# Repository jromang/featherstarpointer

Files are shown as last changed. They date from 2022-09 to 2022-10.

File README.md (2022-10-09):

# Feather Star Pointer

:warning: **Azimuth accuracy is based on a magnetometer : so currently, you can have a 2° error margin in azimuth**

The goal of this project is to be a  simple star pointing system for push-to telescopes, using the [SkySafari Pro](https://skysafariastronomy.com/skysafari-7-professional-astronomy-telescope-control-software-for-android.html) application on your smartphone.

### Components
- [Adafruit Featherboard ESP32 V2](https://www.adafruit.com/product/5400)
- [Adafruit BNO055 Absolute Orientation Sensor](https://learn.adafruit.com/adafruit-bno055-absolute-orientation-sensor)
- [STEMMA QT / Qwiic JST SH 4-Pin Cable - 50mm Long](https://www.adafruit.com/product/4399)
- [Lithium Ion Polymer Battery](https://www.adafruit.com/product/3898)
- 3D printed case and holder (you will find [ready to print STL](https://github.com/jromang/featherstarpointer/tree/main/stl) files in this repo)
- A smartphone (Android/IOS) with the [SkySafari Pro](https://skysafariastronomy.com/skysafari-7-professional-astronomy-telescope-control-software-for-android.html) application
- Optional [Jack JST PH 2.0/2.0mm Male/Female](https://fr.aliexpress.com/item/1005002657347265.html?spm=a2g0o.order_list.0.0.21ef5e5bcTvBVH)
- Optional [Self locking switch](https://fr.aliexpress.com/item/4000164264475.html?spm=a2g0o.order_list.0.0.6cba5e5b0LTYn6)

### How to build
- There is not soldering involved, just connect the Featherboard, the sensor, and the battery with the cable connectors
- You will need to flash the [binary firmware](https://github.com/jromang/featherstarpointer/tree/main/sketch/fsp)  to the Featherboard
- You have to glue the 3D printed base to the 3d printed holder

### How to use
- Follow the [calibration procedure](https://learn.adafruit.com/adafruit-bno055-absolute-orientation-sensor/device-calibration) at startup : the white LED will turn red when the calibration is finished.
- Add the FSP as a 'basic encoder system' in skysafari, choose 'push-to  Alt-az', and connect using bluetooth. Finally set the encoder settings to +8192 (both fields).
- The red LED will start to blink when the battery is low.
- Enjoy !

### Pictures

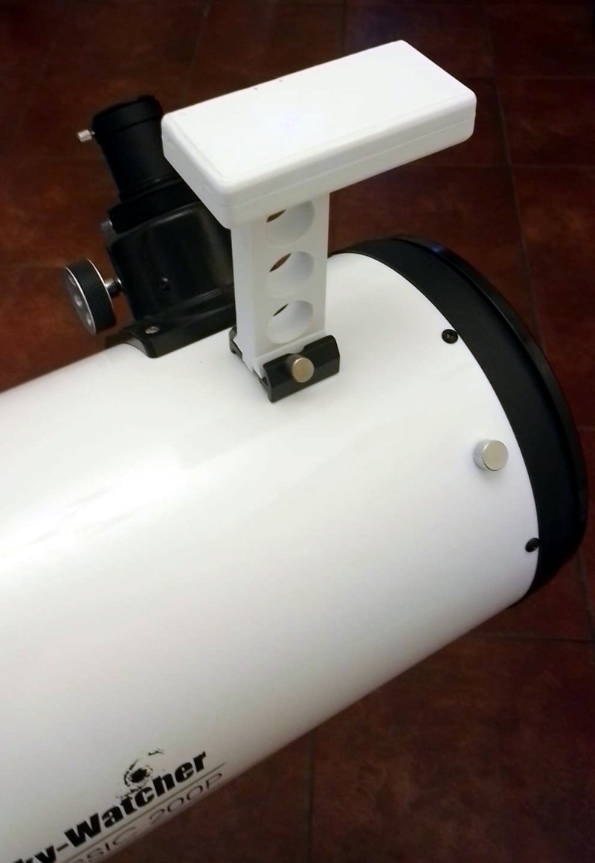
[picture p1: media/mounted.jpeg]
Mounted on scope
 
 
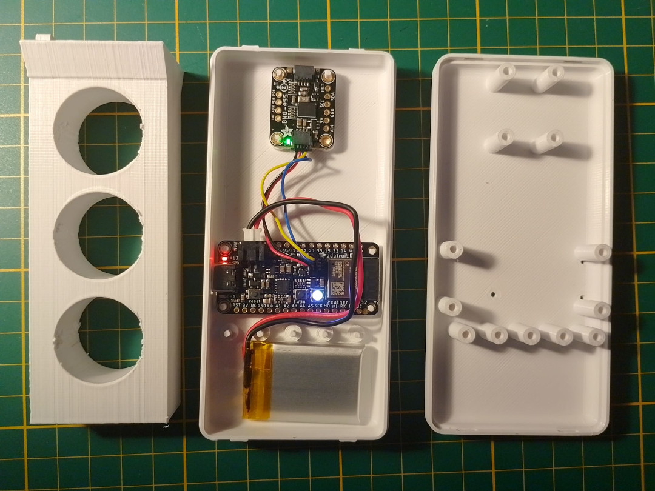
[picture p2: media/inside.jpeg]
Inside
 
 
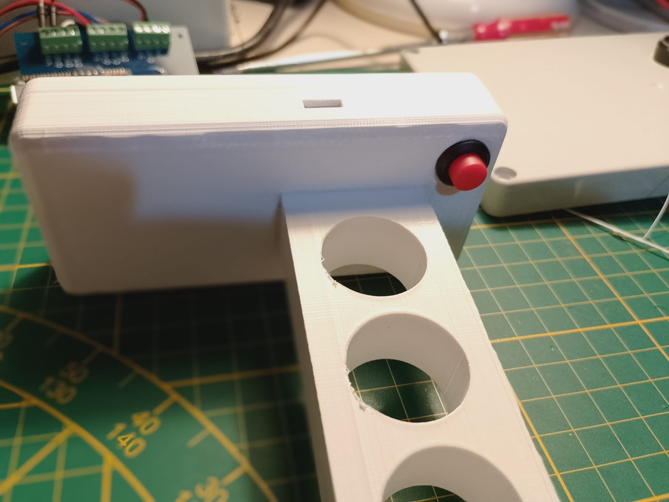
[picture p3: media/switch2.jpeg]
Switch
 
 
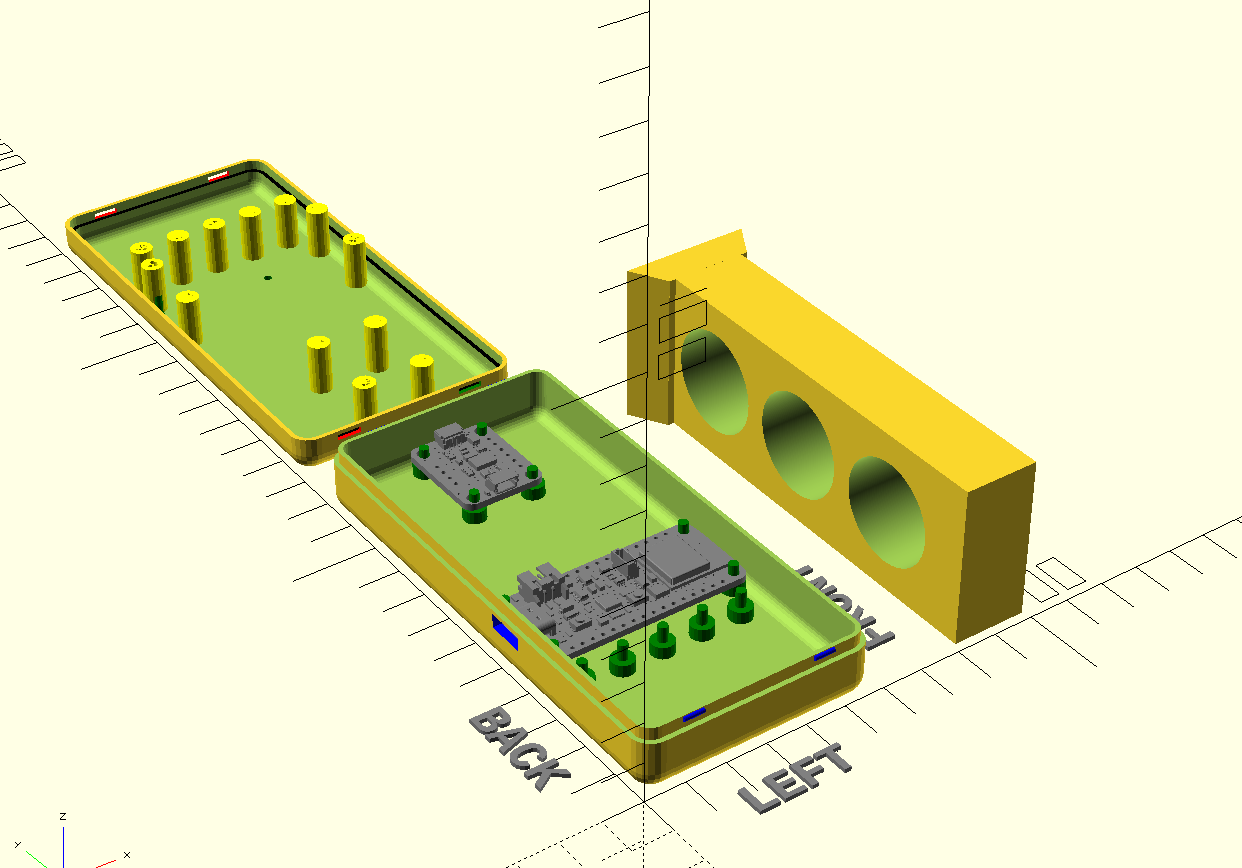
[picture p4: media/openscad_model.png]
3D Model
 
 
 SkySafari

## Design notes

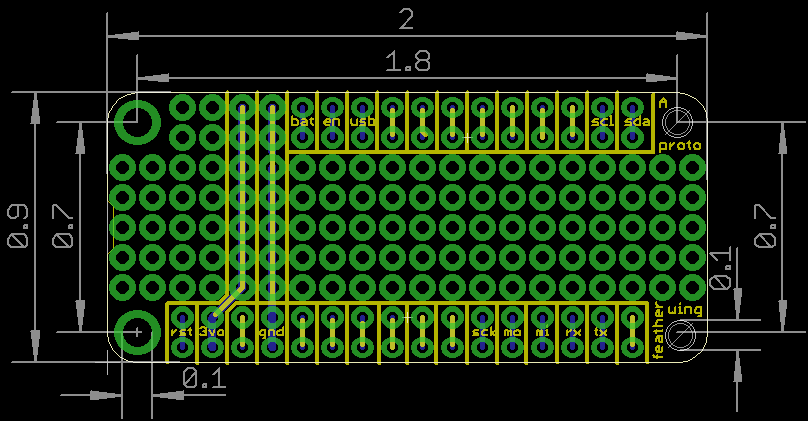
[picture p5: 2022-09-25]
openscad/specs/arduino_adafruit_products_fabprint.png

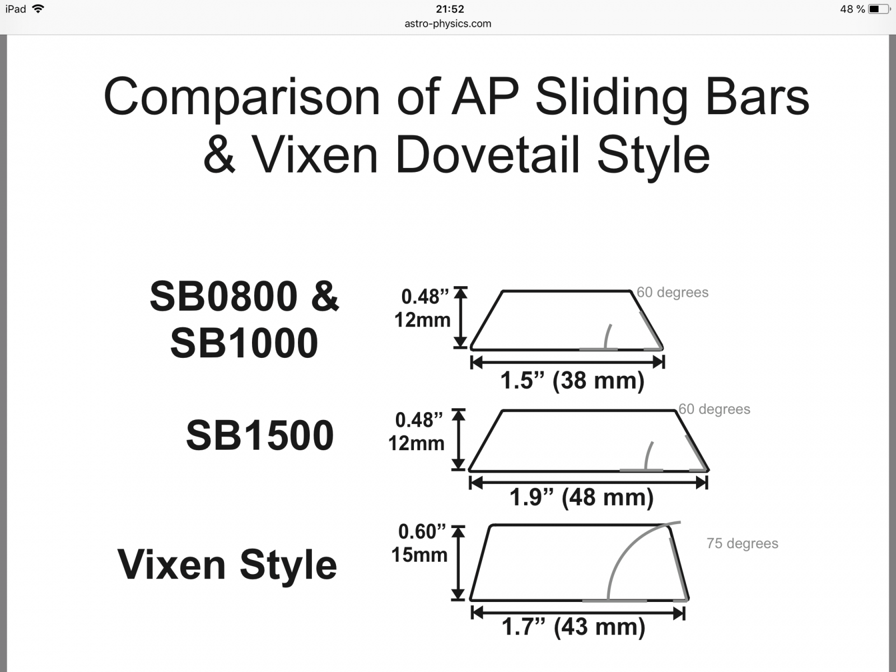
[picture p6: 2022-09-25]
openscad/specs/vixen.png

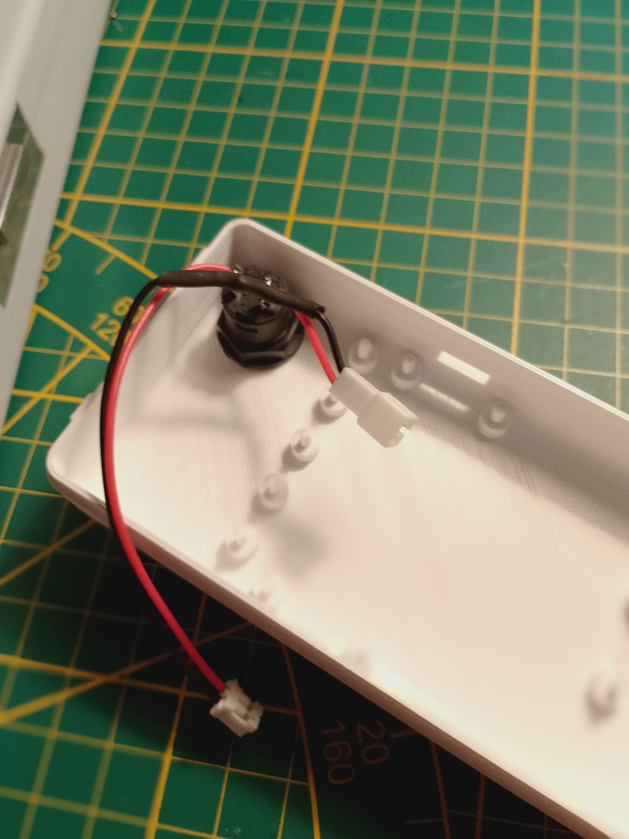
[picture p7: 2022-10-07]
media/switch1.jpeg

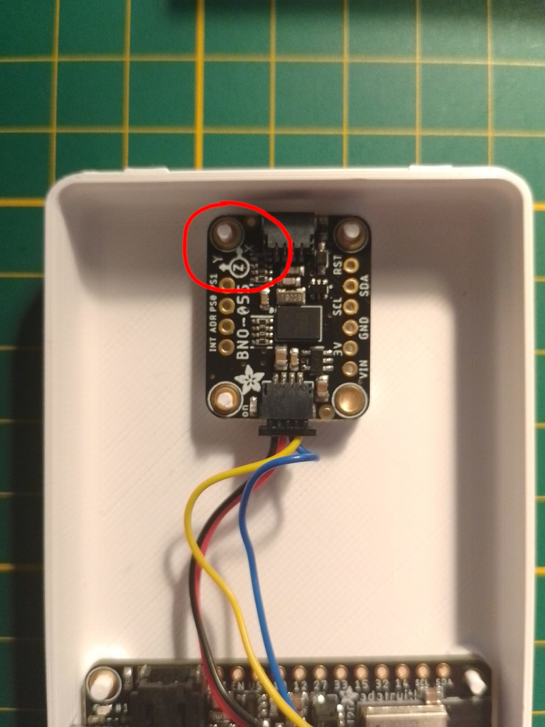
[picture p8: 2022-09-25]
media/sensor_orientation.jpeg

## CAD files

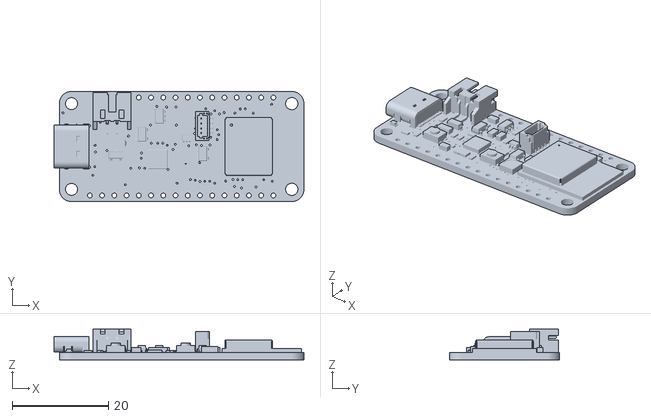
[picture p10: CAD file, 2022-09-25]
openscad/ESP32FeatherV2.stl
51.9 x 22.9 x 6.37

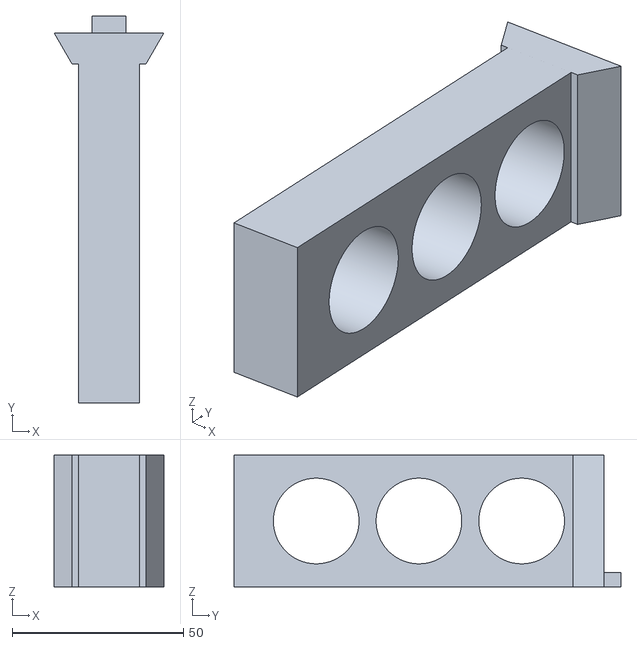
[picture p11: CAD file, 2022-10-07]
stl/holder.stl
32.0 x 113.0 x 38.4

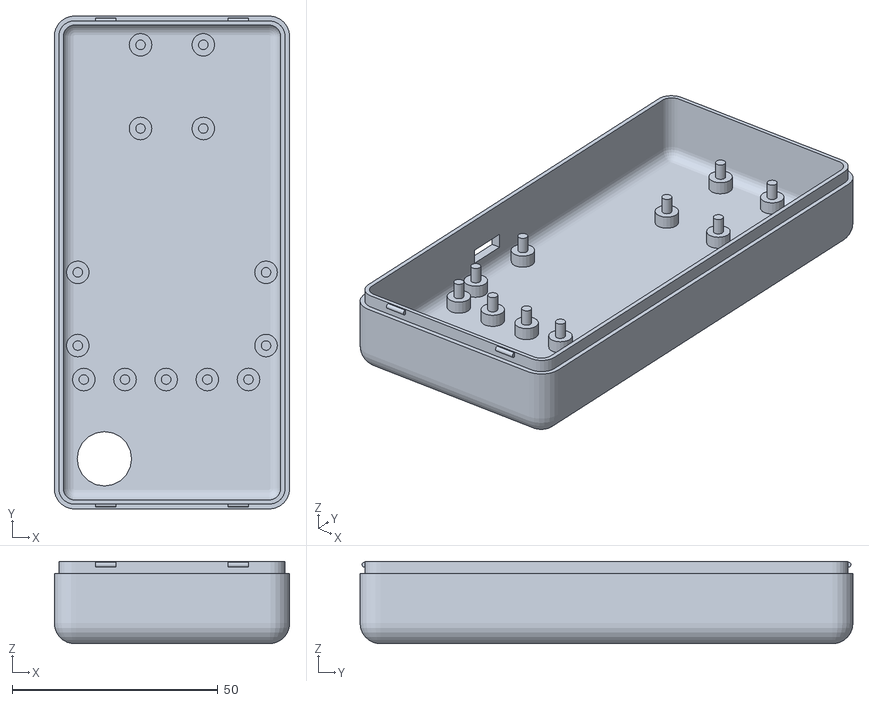
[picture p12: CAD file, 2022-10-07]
stl/base.stl
57.2 x 119.7 x 20.0

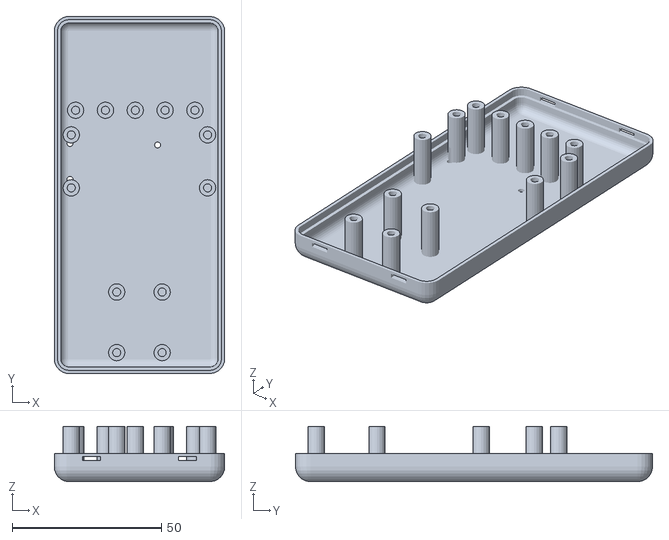
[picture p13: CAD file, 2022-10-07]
stl/lid.stl
57.2 x 119.7 x 18.5

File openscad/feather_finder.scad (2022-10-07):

//https://github.com/mrWheel/YAPP_Box
box_height=7.2;
depth=50;
battery_size=[37,25.5,5.2];
featherboard_size=[50.8,22.8,7.2];
bno055_size=[20.32,25.04,7.2];
cable_length=40;

include <BOSL2/std.scad>
include <BOSL2/joiners.scad>
include<YAPPgenerator_v15.scad>


//-- which part do you want to print?
printBaseShell      = true;
printLidShell       = true;
printHolder         = true;

color("gray")
translate([pcbX,pcbY+battery_size.y+standoffDiameter+2.54/2+1.5 , basePlaneThickness+standoffHeight])
import("ESP32FeatherV2.stl", convexity=3);


//battery
//#color("gray")
//translate([pcbX,pcbY,pcbZ])
//cube(battery_size);


bno_position=[pcbX+featherboard_size.x/2,pcbY+battery_size.y+standoffDiameter+2.54+ cable_length+ featherboard_size.y+standoffDiameter-1.5 , basePlaneThickness+standoffHeight];
color("gray")
translate(bno_position)
rotate([0,0,90])
import("bno055.stl", convexity=3);

difference() {
YAPPgenerate();
//vixen finder dovetail
//https://github.com/revarbat/BOSL2/wiki/joiners.scad#module-dovetail
translate([pcbX+featherboard_size.x/2,40,0])
cube([18.5,39,4], center=true);
//
}

//holder
holder_margin=0.6;
if(printHolder)
translate([90,110,39.4/2])
rotate([90,0,0])
translate([0,0,9])
difference() {
    union() {
    translate([0,-(39-4.2-holder_margin)/2 ,0])   
    cube([10,4.2,28], center=true);
    dovetail("female", width=32, height=9, slide=39-holder_margin, angle=30);
    translate([0,0,49])
    cube([18.5-holder_margin,39-holder_margin,100], center=true);
    }

    for (i = [15, 45, 75]){
        translate([0, 0, i])
        rotate([0,90,0])
        cylinder(  30, d=25, center=true, $fn=360);
    }
}

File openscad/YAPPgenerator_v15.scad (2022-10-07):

/*
***************************************************************************  
**  Yet Another Parameterised Projectbox generator
**
*/
Version="v1.5 (04-09-2022) release candidate 2";
/*
**
**  Copyright (c) 2021, 2022 Willem Aandewiel
**
**  With help from:
**   - Keith Hadley (parameterized label depth)
**   - Oliver Grafe (connectorsPCB)
**
**  TERMS OF USE: MIT License. See base offile.
***************************************************************************      
*/
//---------------------------------------------------------
// This design is parameterized based on the size of a PCB.
//---------------------------------------------------------
// Note: length/lengte refers to X axis, 
//       width/breedte to Y, 
//       height/hoogte to Z

/*
      padding-back|<------pcb length --->|<padding-front
                            RIGHT
        0    X-as ---> 
        +----------------------------------------+   ---
        |                                        |    ^
        |                                        |   padding-right 
        |                                        |    v
        |    -5,y +----------------------+       |   ---              
 B    Y |         | 0,y              x,y |       |     ^              F
 A    - |         |                      |       |     |              R
 C    a |         |                      |       |     | pcb width    O
 K    s |         |                      |       |     |              N
        |         | 0,0              x,0 |       |     v              T
      ^ |    -5,0 +----------------------+       |   ---
      | |                                        |    padding-left
      0 +----------------------------------------+   ---
        0    X-as --->
                          LEFT
*/

//-- which half do you want to print?
printBaseShell      = true;
printLidShell       = true;

//-- Edit these parameters for your own board dimensions
wallThickness       = 2.2;
basePlaneThickness  = 4.0;
lidPlaneThickness   = 2.0;

//-- Total height of box = basePlaneThickness + lidPlaneThickness 
//--                     + baseWallHeight + lidWallHeight
//-- space between pcb and lidPlane :=
//--      (bottonWallHeight+lidWallHeight) - (standoffHeight+pcbThickness)
baseWallHeight      = 16;
lidWallHeight       = 5;

//-- ridge where base and lid off box can overlap
//-- Make sure this isn't less than lidWallHeight
ridgeHeight         = 3.0;
ridgeSlack          = 0.2;
roundRadius         = 5.0;

//-- pcb dimensions
pcbLength           = featherboard_size.x;
pcbWidth            = featherboard_size.y+battery_size.y+bno055_size.y+cable_length;
pcbThickness        = 1.5;

//-- How much the PCB needs to be raised from the base
//-- to leave room for solderings and whatnot
standoffHeight      = 3.0;
pinDiameter         = 2.34;
pinHoleSlack        = 0.2;
standoffDiameter    = 5.5;
                            
//-- padding between pcb and inside wall
paddingFront        = 1;
paddingBack         = 1;
paddingRight        = 1;
paddingLeft         = 1;


//-- D E B U G -----------------//-> Default ---------
showSideBySide      = true;     //-> true
onLidGap            = 3;
shiftLid            = 1;
hideLidWalls        = false;    //-> false
colorLid            = "yellow";   
hideBaseWalls       = false;    //-> false
colorBase           = "white";
showPCB             = false;    //-> false
showMarkers         = false;    //-> false
inspectX            = 0;        //-> 0=none (>0 from front, <0 from back)
inspectY            = 0;        //-> 0=none (>0 from left, <0 from right)
//-- D E B U G ---------------------------------------

/*
********* don't change anything below this line ***************
*/

//-- constants, do not change
yappRectangle   =  0;
yappCircle      =  1;
yappBoth        =  2;
yappLidOnly     =  3;
yappBaseOnly    =  4;
yappHole        =  5;
yappPin         =  6;
yappLeft        =  7;
yappRight       =  8;
yappFront       =  9;
yappBack        = 10;
yappCenter      = 11;
yappSymmetric   = 12;
yappAllCorners  = 13;

//-------------------------------------------------------------------

shellInsideWidth  = pcbWidth+paddingLeft+paddingRight;
shellWidth        = shellInsideWidth+(wallThickness*2)+0;
shellInsideLength = pcbLength+paddingFront+paddingBack;
shellLength       = pcbLength+(wallThickness*2)+paddingFront+paddingBack;
shellInsideHeight = baseWallHeight+lidWallHeight;
shellHeight       = basePlaneThickness+shellInsideHeight+lidPlaneThickness;
pcbX              = wallThickness+paddingBack;
pcbY              = wallThickness+paddingLeft;
pcbYlid           = wallThickness+pcbWidth+paddingRight;
pcbZ              = basePlaneThickness+standoffHeight+pcbThickness;
//pcbZlid           = (baseWallHeight+lidWallHeight+basePlaneThickness)-(standoffHeight);
pcbZlid           = (baseWallHeight+lidWallHeight+lidPlaneThickness)
                        -(standoffHeight+pcbThickness);


//-- pcb_standoffs  -- origin is pcb[0,0,0]
// (0) = posx
// (1) = posy
// (2) = { yappBoth | yappLidOnly | yappBaseOnly }
// (3) = { yappHole, YappPin }
pcbStands =    [
                 //battery
                 [4,  battery_size.y+standoffDiameter/2 , yappBoth, yappPin]
                ,[14,  battery_size.y+standoffDiameter/2 , yappBoth, yappPin]
                ,[24,  battery_size.y+standoffDiameter/2 , yappBoth, yappPin]
                ,[34,  battery_size.y+standoffDiameter/2 , yappBoth, yappPin] 
                ,[44,  battery_size.y+standoffDiameter/2 , yappBoth, yappPin] 

                //featherboard                
                ,[2.54,  battery_size.y+standoffDiameter*2 , yappBoth, yappPin]
                ,[2.54,  battery_size.y+standoffDiameter*2+17.78 , yappBoth, yappPin]
                ,[2.54+45.72,  battery_size.y+standoffDiameter*2 , yappBoth, yappPin]
                ,[2.54+45.72,  battery_size.y+standoffDiameter*2+17.78 , yappBoth, yappPin]
                
                //BNO055
                ,[ pcbLength/2-7.62 , pcbWidth-3.81,  yappBoth, yappPin]
                ,[ pcbLength/2+7.62 , pcbWidth-3.81,  yappBoth, yappPin]
                ,[ pcbLength/2-7.62 , pcbWidth-3.81-20.32,  yappBoth, yappPin]
                ,[ pcbLength/2+7.62 , pcbWidth-3.81-20.32,  yappBoth, yappPin]
                
                
                //,[2.10,  battery_size.y+standoffDiameter*2+2.9 , yappBoth, yappPin]
                //,[2.10,  battery_size.y+standoffDiameter*2+17.78-2.9 , yappBoth, yappPin]
                //,[31.5,  battery_size.y+standoffDiameter*2+3.4 , yappBoth, yappPin]
                
                //   , [20,  20, yappBoth, yappPin] 
                //   , [3,  3, yappBoth, yappPin] 
                //   , [pcbLength-10,  pcbWidth-3, yappBoth, yappPin]
               ];

//-- Lid plane    -- origin is pcb[0,0,0]
// (0) = posx
// (1) = posy
// (2) = width
// (3) = length
// (4) = angle
// (5) = { yappRectangle | yappCircle }
// (6) = { yappCenter }
cutoutsLid  =   [

                 [2.10,  battery_size.y+standoffDiameter*2+2.9, 2, 4, 20, yappCircle]
                ,[2.10,  battery_size.y+standoffDiameter*2+17.78-2.9 , 2, 4, 20, yappCircle]
                ,[31.5,  battery_size.y+standoffDiameter*2+3.4 , 2, 4, 20, yappCircle]
             //     [20, 0, 10, 24, 0, yappRectangle]
             //   , [pcbWidth-6, 40, 12, 4, 20, yappCircle]
             //   , [30, 25, 10, 14, 45, yappRectangle, yappCenter]
                ];

//-- base plane    -- origin is pcb[0,0,0]
// (0) = posx
// (1) = posy
// (2) = width
// (3) = length
// (4) = angle
// (5) = { yappRectangle | yappCircle }
// (6) = { yappCenter }
cutoutsBase =   [
                    [9,  9 , 13.2, 4, 20, yappCircle]
             //       [30, 0, 10, 24, yappRectangle]
             //     , [pcbLength/2, pcbWidth/2, 12, 4, yappCircle]
             //     , [pcbLength-8, 25, 10, 14, yappRectangle, yappCenter]
                ];

//-- front plane  -- origin is pcb[0,0,0]
// (0) = posy
// (1) = posz
// (2) = width
// (3) = height
// (4) = angle
// (5) = { yappRectangle | yappCircle }
// (6) = { yappCenter }
cutoutsFront =  [
              //      [10, 5, 12, 15, 0, yappRectangle]
              //    , [30, 7.5, 15, 9, 0, yappRectangle, yappCenter]
              //    , [0, 2, 10, 0, 0, yappCircle]
                ];

//-- back plane  -- origin is pcb[0,0,0]
// (0) = posy
// (1) = posz
// (2) = width
// (3) = height
// (4) = angle
// (5) = { yappRectangle | yappCircle }
// (6) = { yappCenter }
cutoutsBack =   [
                    [37.5+3, 0, 9.5, 3.5, 0, yappRectangle]
              //    , [30, 0, 10, 8, 0, yappRectangle, yappCenter]
              //    , [pcbWidth, 0, 8, 0, 0, yappCircle]
                ];
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

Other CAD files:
openscad/BOSL2/constants.scad
openscad/BOSL2/nema_steppers.scad
openscad/BOSL2/affine.scad
openscad/BOSL2/attachments.scad
openscad/BOSL2/beziers.scad
openscad/BOSL2/bosl1compat.scad
openscad/BOSL2/bottlecaps.scad
openscad/BOSL2/builtins.scad
openscad/BOSL2/color.scad
openscad/BOSL2/comparisons.scad
openscad/BOSL2/coords.scad
openscad/BOSL2/cubetruss.scad
openscad/BOSL2/distributors.scad
openscad/BOSL2/drawing.scad
openscad/BOSL2/examples/BOSL2logo.scad
openscad/BOSL2/examples/attachments.scad
openscad/BOSL2/examples/boolean_geometry.scad
openscad/BOSL2/examples/fractal_tree.scad
openscad/BOSL2/examples/lsystems.scad
openscad/BOSL2/examples/orientations.scad
openscad/BOSL2/examples/spherical_patch.scad
openscad/BOSL2/fnliterals.scad
openscad/BOSL2/gears.scad
openscad/BOSL2/geometry.scad
openscad/BOSL2/hingesnaps.scad
openscad/BOSL2/joiners.scad
openscad/BOSL2/linalg.scad
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

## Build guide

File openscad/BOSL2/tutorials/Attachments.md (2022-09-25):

# Attachments Tutorial

<!-- TOC -->

## Attachables
BOSL2 introduces the concept of attachables.  Attachables are shapes that can be anchored,
spun, oriented, and attached to other attachables.  The most basic attachable shapes are the
`cube()`, `cylinder()`, `sphere()`, `square()`, and `circle()`.  BOSL2 overrides the built-in
definitions for these shapes, and makes them attachable.

## Anchoring
Anchoring allows you to align a side, edge, or corner of an object with the origin as it is
created.  This is done by passing a vector into the `anchor=` argument.  For roughly cubical
or prismoidal shapes, that vector points in the general direction of the side, edge, or
corner that will be aligned to.  For example, a vector of [1,0,-1] refers to the lower-right
edge of the shape.  Each vector component should be -1, 0, or 1:

```openscad-3D
include <BOSL2/std.scad>
// Anchor at upper-front-left corner
cube([40,30,50], anchor=[-1,-1,1]);
```

```openscad-3D
include <BOSL2/std.scad>
// Anchor at upper-right edge
cube([40,30,50], anchor=[1,0,1]);
```

```openscad-3D
include <BOSL2/std.scad>
// Anchor at bottom face
cube([40,30,50], anchor=[0,0,-1]);
```

Since manually written vectors are not very intuitive, BOSL2 defines some standard directional
vector constants that can be added together:

Constant | Direction | Value
-------- | --------- | -----------
`LEFT`   | X-        | `[-1, 0, 0]`
`RIGHT`  | X+        | `[ 1, 0, 0]`
`FRONT`/`FORWARD`/`FWD` | Y- | `[ 0,-1, 0]`
`BACK`   | Y+        | `[ 0, 1, 0]`
`BOTTOM`/`BOT`/`BTM`/`DOWN` | Z- | `[ 0, 0,-1]` (3D only.)
`TOP`/`UP` | Z+      | `[ 0, 0, 1]` (3D only.)
`CENTER`/`CTR` | Centered | `[ 0, 0, 0]`

If you want a vector pointing towards the bottom-left edge, just add the `BOTTOM` and `LEFT` vector
constants together like `BOTTOM + LEFT`.  Ths will result in a vector of `[-1,0,-1]`.  You can pass
that to the `anchor=` argument for a clearly understandable anchoring:

```openscad-3D
include <BOSL2/std.scad>
cube([40,30,50], anchor=BACK+TOP);
```

```openscad-3D
include <BOSL2/std.scad>
cube([40,30,50], anchor=FRONT);
```

---

For cylindrical type attachables, the Z component of the vector will be -1, 0, or 1, referring
to the bottom rim, the middle side, or the top rim of the cylindrical or conical shape.
The X and Y components can be any value, pointing towards the circular perimeter of the cone.  
These combined let you point at any place on the bottom or top rims, or at an arbitrary
side wall:

```openscad-3D
include <BOSL2/std.scad>
cylinder(r1=25, r2=15, h=60, anchor=TOP+LEFT);
```

```openscad-3D
include <BOSL2/std.scad>
cylinder(r1=25, r2=15, h=60, anchor=BOTTOM+FRONT);
```

```openscad-3D
include <BOSL2/std.scad>
cylinder(r1=25, r2=15, h=60, anchor=UP+spherical_to_xyz(1,30,90));
```

---

For Spherical type attachables, you can pass a vector that points at any arbitrary place on
the surface of the sphere:

```openscad-3D
include <BOSL2/std.scad>
sphere(r=50, anchor=TOP);
```

```openscad-3D
include <BOSL2/std.scad>
sphere(r=50, anchor=TOP+FRONT);
```

```openscad-3D
include <BOSL2/std.scad>
sphere(r=50, anchor=spherical_to_xyz(1,-30,60));
```

---

Some attachable shapes may provide specific named anchors for shape-specific anchoring.  These
will be given as strings and will be specific to that type of attachable.  For example, the
`teardrop()` attachable has a named anchor called "cap":

```openscad-3D
include <BOSL2/std.scad>
teardrop(d=100, l=20, anchor="cap");
```

---

Some shapes, for backwards compatability reasons, can take a `center=` argument.  This just
overrides the `anchor=` argument.  A `center=true` argument is the same as `anchor=CENTER`.
A `center=false` argument can mean `anchor=[-1,-1,-1]` for a cube, or `anchor=BOTTOM` for a
cylinder, to make them behave just like the builtin versions:

```openscad-3D
include <BOSL2/std.scad>
cube([50,40,30],center=true);
```

```openscad-3D
include <BOSL2/std.scad>
cube([50,40,30],center=false);
```

---

Many 2D shapes provided by BOSL2 are also anchorable.  Even the built-in `square()` and `circle()`
modules have been overridden to enable attachability and anchoring.  The `anchor=` options for 2D
shapes can accept 3D vectors, but only the X and Y components will be used:

```openscad-2D
include <BOSL2/std.scad>
square([40,30], anchor=BACK+LEFT);
```

```openscad-2D
include <BOSL2/std.scad>
circle(d=50, anchor=BACK);
```

```openscad-2D
include <BOSL2/std.scad>
hexagon(d=50, anchor=LEFT);
```

```openscad-2D
include <BOSL2/std.scad>
ellipse(d=[50,30], anchor=FRONT);
```

## Spin
Attachable shapes also can be spun in place as you create them.  You can do this by passing the
spin angle (in degrees) into the `spin=` argument.  A positive number will result in a counter-
clockwise spin around the Z axis (as seen from above), and a negative number will make a clockwise
spin:

```openscad-3D
include <BOSL2/std.scad>
cube([20,20,40], center=true, spin=45);
```

You can even spin around each of the three axes in one pass, by giving 3 angles (in degrees) to
`spin=` as a vector, like [Xang,Yang,Zang].  Similarly to `rotate()`, the axes will be spun in
the order given, X-axis spin, then Y-axis, then Z-axis:

```openscad-3D
include <BOSL2/std.scad>
cube([20,20,40], center=true, spin=[10,20,30]);
```

You can also apply spin to 2D shapes from BOSL2, though only by scalar angle:

```openscad-2D
include <BOSL2/std.scad>
square([40,30], spin=30);
```

```openscad-2D
include <BOSL2/std.scad>
ellipse(d=[40,30], spin=30);
```

## Orientation
Another way to specify a rotation for an attachable shape, is to pass a 3D vector via the
`orient=` argument.  This lets you specify what direction to tilt the top of the shape towards.
For example, you can make a cone that is tilted up and to the right like this:

```openscad-3D
include <BOSL2/std.scad>
cylinder(h=100, r1=50, r2=20, orient=UP+RIGHT);
```

You can *not* use `orient=` with 2D shapes.

## Mixing Anchoring, Spin, and Orientation
When giving `anchor=`, `spin=`, and `orient=`, they are applied anchoring first, spin second,
then orient last.  For example, here's a cube:

```openscad-3D
include <BOSL2/std.scad>
cube([20,20,50]);
```

You can center it with an `anchor=CENTER` argument:

```openscad-3D
include <BOSL2/std.scad>
cube([20,20,50], anchor=CENTER);
```

Add a 45 degree spin:

```openscad-3D
include <BOSL2/std.scad>
cube([20,20,50], anchor=CENTER, spin=45);
```

Now tilt the top up and forward:

```openscad-3D
include <BOSL2/std.scad>
cube([20,20,50], anchor=CENTER, spin=45, orient=UP+FWD);
```

Something that may confuse new users is that adding spin to a cylinder may seem nonsensical.
However, since spin is applied *after* anchoring, it can actually have a significant effect:

```openscad-3D
include <BOSL2/std.scad>
cylinder(d=50, l=40, anchor=FWD, spin=-30);
```

For 2D shapes, you can mix `anchor=` with `spin=`, but not with `orient=`.

```openscad-2D
include <BOSL2/std.scad>
square([40,30], anchor=BACK+LEFT, spin=30);
```

## Attaching 3D Children
The reason attachables are called that, is because they can be attached to each other.
You can do that by making one attachable shape be a child of another attachable shape.
By default, the child of an attachable is attached to the center of the parent shape.

```openscad-3D
include <BOSL2/std.scad>
cube(50,center=true)
    cylinder(d1=50,d2=20,l=50);
```

To attach to a different place on the parent, you can use the `attach()` module.  By default,
this will attach the bottom of the child to the given position on the parent.  The orientation
of the child will be overridden to point outwards from the center of the parent, more or less:

```openscad-3D
include <BOSL2/std.scad>
cube(50,center=true)
    attach(TOP) cylinder(d1=50,d2=20,l=20);
```

If you give `attach()` a second anchor argument, it attaches that anchor on the child to the
first anchor on the parent:

```openscad-3D
include <BOSL2/std.scad>
cube(50,center=true)
    attach(TOP,TOP) cylinder(d1=50,d2=20,l=20);
```

By default, `attach()` places the child exactly flush with the surface of the parent.  Sometimes
it's useful to have the child overlap the parent by insetting a bit.  You can do this with the
`overlap=` argument to `attach()`.  A positive value will inset the child into the parent, and
a negative value will outset out from the parent:

```openscad-3D
include <BOSL2/std.scad>
cube(50,center=true)
    attach(TOP,overlap=10)
        cylinder(d=20,l=20);
```

```openscad-3D
include <BOSL2/std.scad>
cube(50,center=true)
    attach(TOP,overlap=-20)
        cylinder(d=20,l=20);
```

If you want to position the child at the parent's anchorpoint, without re-orienting, you can
use the `position()` module:

```openscad-3D
include <BOSL2/std.scad>
cube(50,center=true)
    position(RIGHT) cylinder(d1=50,d2=20,l=20);
```

You can attach or position more than one child at a time by enclosing them all in braces:

```openscad-3D
include <BOSL2/std.scad>
cube(50, center=true) {
    attach(TOP) cylinder(d1=50,d2=20,l=20);
    position(RIGHT) cylinder(d1=50,d2=20,l=20);
}
```

If you want to attach the same shape to multiple places on the same parent, you can pass the
desired anchors as a list to the `attach()` or `position()` modules:

```openscad-3D
include <BOSL2/std.scad>
cube(50, center=true)
    attach([RIGHT,FRONT],TOP) cylinder(d1=50,d2=20,l=20);
```

```openscad-3D
include <BOSL2/std.scad>
cube(50, center=true)
    position([TOP,RIGHT,FRONT]) cylinder(d1=50,d2=20,l=20);
```

## Attaching 2D Children
You can use attachments in 2D as well, but only in the XY plane:

```openscad-2D
include <BOSL2/std.scad>
square(50,center=true)
    attach(RIGHT,FRONT)
        trapezoid(w1=30,w2=0,h=30);
```

```openscad-2D
include <BOSL2/std.scad>
circle(d=50)
    attach(BACK,FRONT,overlap=5)
        trapezoid(w1=30,w2=0,h=30);
```

## Anchor Arrows
One way that is useful to show the position and orientation of an anchorpoint is by attaching
an anchor arrow to that anchor.

```openscad-3D
include <BOSL2/std.scad>
cube(40, center=true)
    attach(LEFT+TOP)
        anchor_arrow();
```

For large objects, you can change the size of the arrow with the `s=` argument.

```openscad-3D
include <BOSL2/std.scad>
sphere(d=100)
    attach(LEFT+TOP)
        anchor_arrow(s=30);
```

To show all the standard cardinal anchorpoints, you can use the `show_anchors()` module.

```openscad-3D
include <BOSL2/std.scad>
cube(40, center=true)
    show_anchors();
```

```openscad-3D
include <BOSL2/std.scad>
cylinder(h=40, d=40, center=true)
    show_anchors();
```

```openscad-3D
include <BOSL2/std.scad>
sphere(d=40)
    show_anchors();
```

For large objects, you can again change the size of the arrows with the `s=` argument.

```openscad-3D
include <BOSL2/std.scad>
cylinder(h=100, d=100, center=true)
    show_anchors(s=30);
```

## Tagged Operations
BOSL2 introduces the concept of tags.  Tags are names that can be given to attachables, so that
you can refer to them when performing `diff()`, `intersect()`, and `conv_hull()` operations.

### `diff(remove, <keep>)`
The `diff()` operator is used to difference away all shapes marked with the tag(s) given to
`remove=`, from the other shapes.  

For example, to difference away a child cylinder from the middle of a parent cube, you can
do this:

```openscad-3D
include <BOSL2/std.scad>
diff("hole")
cube(100, center=true)
    tag("hole")cylinder(h=101, d=50, center=true);
```

The `keep=` argument takes tags for shapes that you want to keep in the output.

```openscad-3D
include <BOSL2/std.scad>
diff("dish", keep="antenna")
cube(100, center=true)
    attach([FRONT,TOP], overlap=33) {
        tag("dish") cylinder(h=33.1, d1=0, d2=95);
        tag("antenna") cylinder(h=33.1, d=10);
    }
```

Remember that tags are inherited by children.  In this case, we need to explicitly
untag the first cylinder (or change its tag to something else), or it
will inherit the "keep" tag and get kept.  

```openscad-3D
include <BOSL2/std.scad>
diff("hole", "keep")
tag("keep")cube(100, center=true)
    attach([RIGHT,TOP]) {
        tag("") cylinder(d=95, h=5);
        tag("hole") cylinder(d=50, h=11, anchor=CTR);
    }
```

If you need to mark multiple children with a tag, you can use the `tag()` module.

```openscad-3D
include <BOSL2/std.scad>
diff("hole")
cube(100, center=true)
    attach([FRONT,TOP], overlap=20)
        tag("hole") {
            cylinder(h=20.1, d1=0, d2=95);
            down(10) cylinder(h=30, d=30);
        }
```

The parent object can be differenced away from other shapes.  Tags are inherited by children,
though, so you will need to set the tags of the children as well as the parent.

```openscad-3D
include <BOSL2/std.scad>
diff("hole")
cube([20,11,45], center=true, $tag="hole")
    cube([40,10,90], center=true, $tag="body");
```

Tags (and therefore tag-based operations like `diff()`) only work correctly with attachable
children.  However, a number of built-in modules for making shapes are *not* attachable.
Some notable non-attachable modules are `text()`, `linear_extrude()`, `rotate_extrude()`,
`polygon()`, `polyhedron()`, `import()`, `surface()`, `union()`, `difference()`,
`intersection()`, `offset()`, `hull()`, and `minkowski()`.

To allow you to use tags-based operations with non-attachable shapes, you can wrap them with the
`force_tag()` module to specify their tags.  For example:

```openscad-3D
include <BOSL2/std.scad>
diff("hole")
cuboid(50)
  attach(TOP)
    force_tag("hole")
      rotate_extrude()
        right(15)
          square(10,center=true);
```

### `intersect(a, <b>, <keep>)`

To perform an intersection of attachables, you can use the `intersect()` module.  If given one
argument to `a=`, the parent and all children *not* tagged with that will be intersected by
everything that *is* tagged with it.

```openscad-3D
include <BOSL2/std.scad>
intersect("bounds")
cube(100, center=true)
    cylinder(h=100, d1=120, d2=95, center=true, $fn=72, $tag="bounds");
```

If given both the `a=` and `b=` arguments, then shapes marked with tags given to `a=` will be
intersected with shapes marked with tags given to `b=`, then unioned with all other shapes.

```openscad-3D
include <BOSL2/std.scad>
intersect("pole", "cap")
cube(100, center=true)
    attach([TOP,RIGHT]) {
        cube([40,40,80],center=true, $tag="pole");
        sphere(d=40*sqrt(2), $tag="cap");
    }
```

If the `keep=` argument is given, anything marked with tags passed to it will be unioned with
the result of the union:

```openscad-3D
include <BOSL2/std.scad>
intersect("bounds", keep="pole")
cube(100, center=true) {
    cylinder(h=100, d1=120, d2=95, center=true, $fn=72, $tag="bounds");
    zrot(45) xcyl(h=140, d=20, $fn=36, $tag="pole");
}
```

### `conv_hull(keep)`
You can use the `conv_hull()` module to hull shapes together the
shapes not marked with the keep tags, before unioning the keep shapes
into the final result. 

```openscad-3D
include <BOSL2/std.scad>
conv_hull("pole")
cube(50, center=true, $tag="hull") {
    cyl(h=100, d=20);
    xcyl(h=100, d=20, $tag="pole");
}
```

## 3D Masking Attachments
To make it easier to mask away shapes from various edges of an attachable parent shape, there
are a few specialized alternatives to the `attach()` and `position()` modules.

### `edge_mask()`
If you have a 3D mask shape that you want to difference away from various edges, you can use
the `edge_mask()` module.  This module will take a vertically oriented shape, and will rotate
and move it such that the BACK, RIGHT (X+,Y+) side of the shape will be aligned with the given
edges.  The shape will be tagged as a "remove" so that you can use
`diff()` with its default "remove" tag.  For example,
here's a shape for rounding an edge:

```openscad-3D
include <BOSL2/std.scad>
module round_edge(l,r) difference() {
    translate([-1,-1,-l/2])
        cube([r+1,r+1,l]);
    translate([r,r])
        cylinder(h=l+1,r=r,center=true, $fn=quantup(segs(r),4));
}
round_edge(l=30, r=19);
```

You can use that mask to round various edges of a cube:

```openscad-3D
include <BOSL2/std.scad>
module round_edge(l,r) difference() {
    translate([-1,-1,-l/2])
        cube([r+1,r+1,l]);
    translate([r,r])
        cylinder(h=l+1,r=r,center=true, $fn=quantup(segs(r),4));
}
diff()
cube([50,60,70],center=true)
    edge_mask([TOP,"Z"],except=[BACK,TOP+LEFT])
        round_edge(l=71,r=10);
```

### `corner_mask()`
If you have a 3D mask shape that you want to difference away from various corners, you can use
the `corner_mask()` module.  This module will take a shape and rotate and move it such that the
BACK RIGHT TOP (X+,Y+,Z+) side of the shape will be aligned with the given corner.  The shape
will be tagged as a "remove" so that you can use `diff()` with its
default "remove" tag.  For example, here's a shape for
rounding a corner:

```openscad-3D
include <BOSL2/std.scad>
module round_corner(r) difference() {
    translate(-[1,1,1])
        cube(r+1);
    translate([r,r,r])
        sphere(r=r, style="aligned", $fn=quantup(segs(r),4));
}
round_corner(r=10);
```

You can use that mask to round various corners of a cube:

```openscad-3D
include <BOSL2/std.scad>
module round_corner(r) difference() {
    translate(-[1,1,1])
        cube(r+1);
    translate([r,r,r])
        sphere(r=r, style="aligned", $fn=quantup(segs(r),4));
}
diff()
cube([50,60,70],center=true)
    corner_mask([TOP,FRONT],LEFT+FRONT+TOP)
        round_corner(r=10);
```

### Mix and Match Masks
You can use `edge_mask()` and `corner_mask()` together as well:

```openscad-3D
include <BOSL2/std.scad>
module round_corner(r) difference() {
    translate(-[1,1,1])
        cube(r+1);
    translate([r,r,r])
        sphere(r=r, style="aligned", $fn=quantup(segs(r),4));
}
module round_edge(l,r) difference() {
    translate([-1,-1,-l/2])
        cube([r+1,r+1,l]);
    translate([r,r])
        cylinder(h=l+1,r=r,center=true, $fn=quantup(segs(r),4));
}
diff()
cube([50,60,70],center=true) {
    edge_mask("ALL") round_edge(l=71,r=10);
    corner_mask("ALL") round_corner(r=10);
}
```

## 2D Profile Mask Attachments
While 3D mask shapes give you a great deal of control, you need to make sure they are correctly
sized, and you need to provide separate mask shapes for corners and edges.  Often, a single 2D
profile could be used to describe the edge mask shape (via `linear_extrude()`), and the corner
mask shape (via `rotate_extrude()`).  This is where `edge_profile()`, `corner_profile()`, and
`face_profile()` come in.

### `edge_profile()`
Using the `edge_profile()` module, you can provide a 2D profile shape and it will be linearly
extruded to a mask of the apropriate length for each given edge.  The resultant mask will be
tagged with "remove" so that you can difference it away with `diff()`
with the default "remove" tag.  The 2D profile is
assumed to be oriented with the BACK, RIGHT (X+,Y+) quadrant as the "cutter edge" that gets
re-oriented towards the edges of the parent shape.  A typical mask profile for chamfering an
edge may look like:

```openscad-2D
include <BOSL2/std.scad>
mask2d_roundover(10);
```

Using that mask profile, you can mask the edges of a cube like:

```openscad-3D
include <BOSL2/std.scad>
diff()
cube([50,60,70],center=true)
   edge_profile("ALL")
       mask2d_roundover(10);
```

### `corner_profile()`
You can use the same profile to make a rounded corner mask as well:

```openscad-3D
include <BOSL2/std.scad>
diff()
cube([50,60,70],center=true)
   corner_profile("ALL", r=10)
       mask2d_roundover(10);
```

### `face_profile()`
As a simple shortcut to apply a profile mask to all edges and corners of a face, you can use the
`face_profile()` module:

```openscad-3D
include <BOSL2/std.scad>
diff()
cube([50,60,70],center=true)
   face_profile(TOP, r=10)
       mask2d_roundover(10);
```

## Coloring Attachables
Usually, when coloring a shape with the `color()` module, the parent color overrides the colors of
all children.  This is often not what you want:

```openscad-3D
include <BOSL2/std.scad>
$fn = 24;
color("red") spheroid(d=3) {
    attach(CENTER,BOT) color("white") cyl(h=10, d=1) {
        attach(TOP,BOT) color("green") cyl(h=5, d1=3, d2=0);
    }
}
```

If you use the `recolor()` module, however, the child's color overrides the color of the parent.
This is probably easier to understand by example:

```openscad-3D
include <BOSL2/std.scad>
$fn = 24;
recolor("red") spheroid(d=3) {
    attach(CENTER,BOT) recolor("white") cyl(h=10, d=1) {
        attach(TOP,BOT) recolor("green") cyl(h=5, d1=3, d2=0);
    }
}
```

## Making Attachables
To make a shape attachable, you just need to wrap it with an `attachable()` module with a
basic description of the shape's geometry.  By default, the shape is expected to be centered
at the origin.  The `attachable()` module expects exactly two children.  The first will be
the shape to make attachable, and the second will be `children()`, literally.

### Prismoidal/Cuboidal Attachables
To make a cuboidal or prismoidal shape attachable, you use the `size`, `size2`, and `offset`
arguments of `attachable()`.

In the most basic form, where the shape is fully cuboid, with top and bottom of the same size,
and directly over one another, you can just use `size=`.

```openscad-3D
include <BOSL2/std.scad>
module cubic_barbell(s=100, anchor=CENTER, spin=0, orient=UP) {
    attachable(anchor,spin,orient, size=[s*3,s,s]) {
        union() {
            xcopies(2*s) cube(s, center=true);
            xcyl(h=2*s, d=s/4);
        }
        children();
    }
}
cubic_barbell(100) show_anchors(30);
```

When the shape is prismoidal, where the top is a different size from the bottom, you can use
the `size2=` argument as well. While `size=` takes all three axes sizes, the `size2=` argument
only takes the [X,Y] sizes of the top of the shape.

```openscad-3D
include <BOSL2/std.scad>
module prismoidal(size=[100,100,100], scale=0.5, anchor=CENTER, spin=0, orient=UP) {
    attachable(anchor,spin,orient, size=size, size2=[size.x, size.y]*scale) {
        hull() {
            up(size.z/2-0.005)
                linear_extrude(height=0.01, center=true)
                    square([size.x,size.y]*scale, center=true);
            down(size.z/2-0.005)
                linear_extrude(height=0.01, center=true)
                    square([size.x,size.y], center=true);
        }
        children();
    }
}
prismoidal([100,60,30], scale=0.5) show_anchors(20);
```

When the top of the prismoid can be shifted away from directly above the bottom, you can use
the `shift=` argument.  The `shift=` argument takes an [X,Y] vector of the offset of the center
of the top from the XY center of the bottom of the shape.

```openscad-3D
include <BOSL2/std.scad>
module prismoidal(size=[100,100,100], scale=0.5, shift=[0,0], anchor=CENTER, spin=0, orient=UP) {
    attachable(anchor,spin,orient, size=size, size2=[size.x, size.y]*scale, shift=shift) {
        hull() {
            translate([shift.x, shift.y, size.z/2-0.005])
                linear_extrude(height=0.01, center=true)
                    square([size.x,size.y]*scale, center=true);
            down(size.z/2-0.005)
                linear_extrude(height=0.01, center=true)
                    square([size.x,size.y], center=true);
        }
        children();
    }
}
prismoidal([100,60,30], scale=0.5, shift=[-30,20]) show_anchors(20);
```

In the case that the prismoid is not oriented vertically, (ie, where the `shift=` or `size2=`
arguments should refer to a plane other than XY) you can use the `axis=` argument.  This lets
you make prismoids naturally oriented forwards/backwards or sideways.

```openscad-3D
include <BOSL2/std.scad>
module yprismoidal(
    size=[100,100,100], scale=0.5, shift=[0,0],
    anchor=CENTER, spin=0, orient=UP
) {
    attachable(
        anchor, spin, orient,
        size=size, size2=point2d(size)*scale,
        shift=shift, axis=BACK
    ) {
        xrot(-90) hull() {
            translate([shift.x, shift.y, size.z/2-0.005])
                linear_extrude(height=0.01, center=true)
                    square([size.x,size.y]*scale, center=true);
            down(size.z/2-0.005)
                linear_extrude(height=0.01, center=true)
                    square([size.x,size.y], center=true);
        }
        children();
    }
}
yprismoidal([100,60,30], scale=1.5, shift=[20,20]) show_anchors(20);
```

### Cylindrical Attachables
To make a cylindrical shape attachable, you use the `l`, and `r`/`d`, args of `attachable()`.

```openscad-3D
include <BOSL2/std.scad>
module twistar(l,r,d, anchor=CENTER, spin=0, orient=UP) {
    r = get_radius(r=r,d=d,dflt=1);
    attachable(anchor,spin,orient, r=r, l=l) {
        linear_extrude(height=l, twist=90, slices=20, center=true, convexity=4)
            star(n=20, r=r, ir=r*0.9);
        children();
    }
}
twistar(l=100, r=40) show_anchors(20);
```

If the cylinder is elipsoidal in shape, you can pass the inequal X/Y sizes as a 2-item vector
to the `r=` or `d=` argument.

```openscad-3D
include <BOSL2/std.scad>
module ovalstar(l,rx,ry, anchor=CENTER, spin=0, orient=UP) {
    attachable(anchor,spin,orient, r=[rx,ry], l=l) {
        linear_extrude(height=l, center=true, convexity=4)
            scale([1,ry/rx,1])
                star(n=20, r=rx, ir=rx*0.9);
        children();
    }
}
ovalstar(l=100, rx=50, ry=30) show_anchors(20);
```

For cylindrical shapes that arent oriented vertically, use the `axis=` argument.

```openscad-3D
include <BOSL2/std.scad>
module ytwistar(l,r,d, anchor=CENTER, spin=0, orient=UP) {
    r = get_radius(r=r,d=d,dflt=1);
    attachable(anchor,spin,orient, r=r, l=l, axis=BACK) {
        xrot(-90)
            linear_extrude(height=l, twist=90, slices=20, center=true, convexity=4)
                star(n=20, r=r, ir=r*0.9);
        children();
    }
}
ytwistar(l=100, r=40) show_anchors(20);
```

### Conical Attachables
To make a conical shape attachable, you use the `l`, `r1`/`d1`, and `r2`/`d2`, args of
`attachable()`.

```openscad-3D
include <BOSL2/std.scad>
module twistar(l, r,r1,r2, d,d1,d2, anchor=CENTER, spin=0, orient=UP) {
    r1 = get_radius(r1=r1,r=r,d1=d1,d=d,dflt=1);
    r2 = get_radius(r1=r2,r=r,d1=d2,d=d,dflt=1);
    attachable(anchor,spin,orient, r1=r1, r2=r2, l=l) {
        linear_extrude(height=l, twist=90, scale=r2/r1, slices=20, center=true, convexity=4)
            star(n=20, r=r1, ir=r1*0.9);
        children();
    }
}
twistar(l=100, r1=40, r2=20) show_anchors(20);
```

If the cone is ellipsoidal in shape, you can pass the inequal X/Y sizes as a 2-item vectors
to the `r1=`/`r2=` or `d1=`/`d2=` arguments.

```openscad-3D
include <BOSL2/std.scad>
module ovalish(l,rx1,ry1,rx2,ry2, anchor=CENTER, spin=0, orient=UP) {
    attachable(anchor,spin,orient, r1=[rx1,ry1], r2=[rx2,ry2], l=l) {
        hull() {
            up(l/2-0.005)
                linear_extrude(height=0.01, center=true)
                    ellipse([rx2,ry2]);
            down(l/2-0.005)
                linear_extrude(height=0.01, center=true)
                    ellipse([rx1,ry1]);
        }
        children();
    }
}
ovalish(l=100, rx1=50, ry1=30, rx2=30, ry2=50) show_anchors(20);
```

For conical shapes that are not oriented vertically, use the `axis=` argument to indicate the
direction of the primary shape axis:

```openscad-3D
include <BOSL2/std.scad>
module ytwistar(l, r,r1,r2, d,d1,d2, anchor=CENTER, spin=0, orient=UP) {
    r1 = get_radius(r1=r1,r=r,d1=d1,d=d,dflt=1);
    r2 = get_radius(r1=r2,r=r,d1=d2,d=d,dflt=1);
    attachable(anchor,spin,orient, r1=r1, r2=r2, l=l, axis=BACK) {
        xrot(-90)
            linear_extrude(height=l, twist=90, scale=r2/r1, slices=20, center=true, convexity=4)
                star(n=20, r=r1, ir=r1*0.9);
        children();
    }
}
ytwistar(l=100, r1=40, r2=20) show_anchors(20);
```

### Spherical Attachables
To make a spherical shape attachable, you use the `r`/`d` args of `attachable()`.

```openscad-3D
include <BOSL2/std.scad>
module spikeball(r, d, anchor=CENTER, spin=0, orient=UP) {
    r = get_radius(r=r,d=d,dflt=1);
    attachable(anchor,spin,orient, r=r*1.1) {
        union() {
            ovoid_spread(r=r, n=512, cone_ang=180) cylinder(r1=r/10, r2=0, h=r/10);
            sphere(r=r);
        }
        children();
    }
}
spikeball(r=50) show_anchors(20);
```

If the shape is more of an ovoid, you can pass a 3-item vector of sizes to `r=` or `d=`.

```openscad-3D
include <BOSL2/std.scad>
module spikeball(r, d, scale, anchor=CENTER, spin=0, orient=UP) {
    r = get_radius(r=r,d=d,dflt=1);
    attachable(anchor,spin,orient, r=r*1.1*scale) {
        union() {
            ovoid_spread(r=r, n=512, scale=scale, cone_ang=180) cylinder(r1=r/10, r2=0, h=r/10);
            scale(scale) sphere(r=r);
        }
        children();
    }
}
spikeball(r=50, scale=[0.75,1,1.5]) show_anchors(20);
```

### VNF Attachables
If the shape just doesn't fit into any of the above categories, and you constructed it as a
[VNF](vnf.scad), you can use the VNF itself to describe the geometry with the `vnf=` argument.

There are two variations to how anchoring can work for VNFs. When `extent=true`, (the default)
then a plane is projected out from the origin, perpendicularly in the direction of the anchor,
to the furthest distance that intersects with the VNF shape.  The anchorpoint is then the
center of the points that still intersect that plane.

```openscad-FlatSpin,VPD=500
include <BOSL2/std.scad>
module stellate_cube(s=100, anchor=CENTER, spin=0, orient=UP) {
    s2 = 3 * s;
    verts = [
        [0,0,-s2*sqrt(2)/2],
        each down(s/2, p=path3d(square(s,center=true))),
        each zrot(45, p=path3d(square(s2,center=true))),
        each up(s/2, p=path3d(square(s,center=true))),
        [0,0,s2*sqrt(2)/2]
    ];
    faces = [
        [0,2,1], [0,3,2], [0,4,3], [0,1,4],
        [1,2,6], [1,6,9], [6,10,9], [2,10,6],
        [1,5,4], [1,9,5], [9,12,5], [5,12,4],
        [4,8,3], [4,12,8], [12,11,8], [11,3,8],
        [2,3,7], [3,11,7], [7,11,10], [2,7,10],
        [9,10,13], [10,11,13], [11,12,13], [12,9,13]
    ];
    vnf = [verts, faces];
    attachable(anchor,spin,orient, vnf=vnf) {
        vnf_polyhedron(vnf);
        children();
    }
}
stellate_cube(25) {
    attach(UP+RIGHT) {
        anchor_arrow(20);
        %cube([100,100,0.1],center=true);
    }
}
```

When `extent=false`, then the anchorpoint will be the furthest intersection of the VNF with
the anchor ray from the origin. The orientation of the anchorpoint will be the normal of the
face at the intersection.  If the intersection is at an edge or corner, then the orientation
will bisect the angles between the faces.

```openscad-VPD=1250
include <BOSL2/std.scad>
module stellate_cube(s=100, anchor=CENTER, spin=0, orient=UP) {
    s2 = 3 * s;
    verts = [
        [0,0,-s2*sqrt(2)/2],
        each down(s/2, p=path3d(square(s,center=true))),
        each zrot(45, p=path3d(square(s2,center=true))),
        each up(s/2, p=path3d(square(s,center=true))),
        [0,0,s2*sqrt(2)/2]
    ];
    faces = [
        [0,2,1], [0,3,2], [0,4,3], [0,1,4],
        [1,2,6], [1,6,9], [6,10,9], [2,10,6],
        [1,5,4], [1,9,5], [9,12,5], [5,12,4],
        [4,8,3], [4,12,8], [12,11,8], [11,3,8],
        [2,3,7], [3,11,7], [7,11,10], [2,7,10],
        [9,10,13], [10,11,13], [11,12,13], [12,9,13]
    ];
    vnf = [verts, faces];
    attachable(anchor,spin,orient, vnf=vnf, extent=false) {
        vnf_polyhedron(vnf);
        children();
    }
}
stellate_cube() show_anchors(50);
```

```openscad-3D
include <BOSL2/std.scad>
$fn=32;
R = difference(circle(10), right(2, circle(9)));
linear_sweep(R,height=10,atype="hull")
    attach(RIGHT) anchor_arrow();
```

## Making Named Anchors
While vector anchors are often useful, sometimes there are logically extra attachment points that
aren't on the perimeter of the shape.  This is what named string anchors are for.  For example,
the `teardrop()` shape uses a cylindrical geometry for it's vector anchors, but it also provides
a named anchor "cap" that is at the tip of the hat of the teardrop shape.

Named anchors are passed as an array of `named_anchor()`s to the `anchors=` argument of `attachable()`.
The `named_anchor()` call takes a name string, a positional point, an orientation vector, and a spin.
The name is the name of the anchor.  The positional point is where the anchorpoint is at.  The
orientation vector is the direction that a child attached at that anchorpoint should be oriented.
The spin is the number of degrees that an attached child should be rotated counter-clockwise around
the orientation vector.  Spin is optional, and defaults to 0.

To make a simple attachable shape similar to a `teardrop()` that provides a "cap" anchor, you may
define it like this:

```openscad-3D
include <BOSL2/std.scad>
module raindrop(r, thick, anchor=CENTER, spin=0, orient=UP) {
    anchors = [
        named_anchor("cap", [0,r/sin(45),0], BACK, 0)
    ];
    attachable(anchor,spin,orient, r=r, l=thick, anchors=anchors) {
        linear_extrude(height=thick, center=true) {
            circle(r=r);
            back(r*sin(45)) zrot(45) square(r, center=true);
        }
        children();
    }
}
raindrop(r=25, thick=20, anchor="cap");
```

If you want multiple named anchors, just add them to the list of anchors:

```openscad-FlatSpin,VPD=150
include <BOSL2/std.scad>
module raindrop(r, thick, anchor=CENTER, spin=0, orient=UP) {
    anchors = [
        named_anchor("captop", [0,r/sin(45), thick/2], BACK+UP,   0),
        named_anchor("cap",    [0,r/sin(45), 0      ], BACK,      0),
        named_anchor("capbot", [0,r/sin(45),-thick/2], BACK+DOWN, 0)
    ];
    attachable(anchor,spin,orient, r=r, l=thick, anchors=anchors) {
        linear_extrude(height=thick, center=true) {
            circle(r=r);
            back(r*sin(45)) zrot(45) square(r, center=true);
        }
        children();
    }
}
raindrop(r=15, thick=10) show_anchors();
```

Sometimes the named anchor you want to add may be at a point that is reached through a complicated
set of translations and rotations.  One quick way to calculate that point is to reproduce those
transformations in a transformation matrix chain.  This is simplified by how you can use the
function forms of almost all the transformation modules to get the transformation matrices, and
chain them together with matrix multiplication.  For example, if you have:

```
scale([1.1, 1.2, 1.3]) xrot(15) zrot(25) right(20) sphere(d=1);
```

and you want to calculate the centerpoint of the sphere, you can do it like:

```
sphere_pt = apply(
    scale([1.1, 1.2, 1.3]) * xrot(15) * zrot(25) * right(20),
    [0,0,0]
);
```

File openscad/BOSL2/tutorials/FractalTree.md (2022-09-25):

# Fractal Tree Tutorial

<!-- TOC -->

### Start with a Tree Trunk

Firstoff, include the BOSL2 library, then make a starting module that just has a tapered cylinder for the tree trunk.

```openscad-3D
include <BOSL2/std.scad>
module tree(l=1500, sc=0.7)
    cylinder(l=l, d1=l/5, d2=l/5*sc);
tree();
```

### Attaching a Branch

You can attach a branch to the top of the trunk by using `attach()` as a child of the trunk cylinder.

```openscad-3D
include <BOSL2/std.scad>
module tree(l=1500, sc=0.7)
    cylinder(l=l, d1=l/5, d2=l/5*sc)
        attach(TOP)
            yrot(30) cylinder(l=l*sc, d1=l/5*sc, d2=l/5*sc*sc);
tree();
```

### Replicating the Branch

Instead of attaching each branch individually, you can make multiple copies of one branch, that are rotated relative to each other.

```openscad-3D
include <BOSL2/std.scad>
module tree(l=1500, sc=0.7)
    cylinder(l=l, d1=l/5, d2=l/5*sc)
        attach(TOP)
            zrot_copies(n=2)  // Replicate that branch
                yrot(30) cylinder(l=l*sc, d1=l/5*sc, d2=l/5*sc*sc);
tree();
```

### Use Recursion

Since branches look much like the main trunk, we can make the tree recursive. Don't forget the termination clause, or else it'll try to recurse forever!

```openscad-Med
include <BOSL2/std.scad>
module tree(l=1500, sc=0.7, depth=10)
    cylinder(l=l, d1=l/5, d2=l/5*sc)
        attach(TOP)
            if (depth>0)  { // Important!
                zrot_copies(n=2)
                yrot(30) tree(depth=depth-1, l=l*sc, sc=sc);
            }
tree();
```

### Make it Not Flat

A flat planar tree isn't what we want, so lets bush it out a bit by rotating each level 90 degrees.

```openscad-Med
include <BOSL2/std.scad>
module tree(l=1500, sc=0.7, depth=10)
    cylinder(l=l, d1=l/5, d2=l/5*sc)
        attach(TOP)
            if (depth>0) {
                zrot(90)  // Bush it out
                zrot_copies(n=2)
                yrot(30) tree(depth=depth-1, l=l*sc, sc=sc);
            }
tree();
```

### Adding Leaves

Let's add leaves. They look much like squashed versions of the standard teardrop() module, so lets use that.

```openscad-Big
include <BOSL2/std.scad>
module tree(l=1500, sc=0.7, depth=10)
    cylinder(l=l, d1=l/5, d2=l/5*sc)
        attach(TOP)
            if (depth>0) {
                zrot(90)
                zrot_copies(n=2)
                yrot(30) tree(depth=depth-1, l=l*sc, sc=sc);
            } else {
                yscale(0.67)
                teardrop(d=l*3, l=1, anchor=BOT, spin=90);
            }
tree();
```

### Adding Color

We can finish this off with some color. The `color()` module will force all it's children and
their descendants to the new color, even if they were colored before. The `recolor()` module,
however, will only color children and decendants that don't already have a color set by a more
nested `recolor()`.

```openscad-Big
include <BOSL2/std.scad>
module tree(l=1500, sc=0.7, depth=10)
    recolor("lightgray")
    cylinder(l=l, d1=l/5, d2=l/5*sc)
        attach(TOP)
            if (depth>0) {
                zrot(90)
                zrot_copies(n=2)
                yrot(30) tree(depth=depth-1, l=l*sc, sc=sc);
            } else {
                recolor("springgreen")
                yscale(0.67)
                teardrop(d=l*3, l=1, anchor=BOT, spin=90);
            }
tree();
```

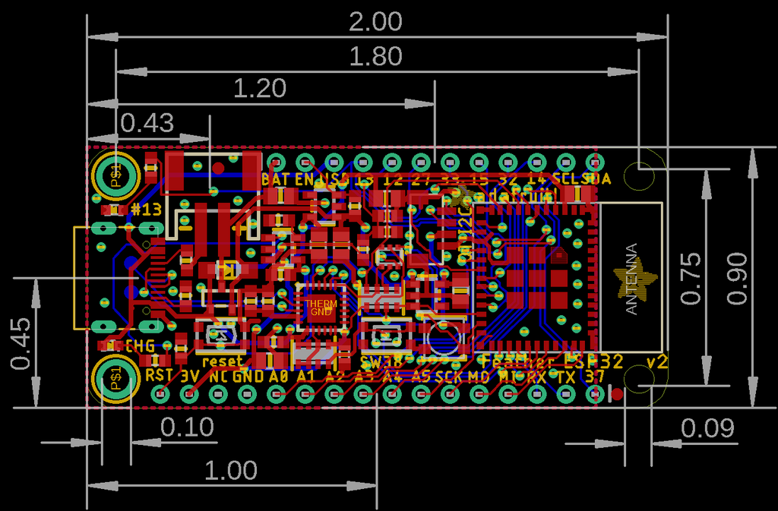
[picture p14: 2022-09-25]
openscad/specs/adafruit_products_FV2_fab_print.png

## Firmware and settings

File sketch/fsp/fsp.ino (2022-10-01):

/* 
 * This file is part of the Feather Star Pointer distribution 
 * (https://github.com/jromang/featherstarpointer).
 * Copyright (c) 2022 Jean-Francois ROMANG.
 * 
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
 * You should have received a copy of the GNU General Public License 
 * along with this program. If not, see <http://www.gnu.org/licenses/>.
 */

#include <Wire.h>
#include <Adafruit_Sensor.h>
#include <Adafruit_BNO055.h>
#include <WS2812FX.h>
#include <BluetoothSerial.h>
#include <SimpleTimer.h>

#if !defined(CONFIG_BT_ENABLED) || !defined(CONFIG_BLUEDROID_ENABLED)
#error Bluetooth is not enabled! Please run `make menuconfig` to and enable it
#endif

#if !defined(CONFIG_BT_SPP_ENABLED)
#error Serial Bluetooth not available or not enabled. It is only available for the ESP32 chip.
#endif

#define VBATPIN A13

Adafruit_BNO055 bno = Adafruit_BNO055(55);
WS2812FX ws2812fx = WS2812FX(1, PIN_NEOPIXEL, NEO_GRB + NEO_KHZ800);
BluetoothSerial SerialBT;

SimpleTimer batteryTimer(60000);

// Modulo working with negative numbers
int mod(int a, int b)
{
    int r = a % b;
    return r < 0 ? r + b : r;
}

// Calibration procedure at startup
/* 
  https://learn.adafruit.com/adafruit-bno055-absolute-orientation-sensor/device-calibration
  To generate valid calibration data, the following criteria should be met:

  Gyroscope: The device must be standing still in any position
  Magnetometer: In the past 'figure 8' motions were required in 3 dimensions, but with recent devices
  fast magnetic compensation takes place with sufficient normal movement of the device
  Accelerometer: The BNO055 must be placed in 6 standing positions for +X, -X, +Y, -Y, +Z and -Z.
  This is the most onerous sensor to calibrate, but the best solution to generate the calibration data
  is to find a block of wood or similar object, and place the sensor on each of the 6 'faces' of the block,
  which will help to maintain sensor alignment during the calibration process.  You should still be able to
  get reasonable quality data from the BNO055, however, even if the accelerometer isn't entirely
  or perfectly calibrated.
*/
void calibrate()
{
  Serial.println("Calibration start");
  SerialBT.println("Calibration start");
  /* Get the four calibration values (0..3) */
  /* Any sensor data reporting 0 should be ignored, */
  /* 3 means 'fully calibrated" */
  uint8_t system, gyro, accel, mag;
  system = gyro = accel = mag = 0;

  ws2812fx.setColor(GRAY);
  ws2812fx.service();

  while(system!=3 || gyro!= 3 || accel!=3 || mag!=3)
  {
    bno.getCalibration(&system, &gyro, &accel, &mag);
    if(system)
    {
      /* Display the individual values */
      Serial.print("Sys:");
      Serial.print(system, DEC);
      Serial.print(" G:");
      Serial.print(gyro, DEC);
      Serial.print(" A:");
      Serial.print(accel, DEC);
      Serial.print(" M:");
      Serial.println(mag, DEC);

      SerialBT.print("Sys:");
      SerialBT.print(system, DEC);
      SerialBT.print(" G:");
      SerialBT.print(gyro, DEC);
      SerialBT.print(" A:");
      SerialBT.print(accel, DEC);
      SerialBT.print(" M:");
      SerialBT.println(mag, DEC);
    }
    delay(200);
  }
  Serial.println("Calibration OK");
  SerialBT.println("Calibration OK");
}

void displayBatteryCharge()
{
      float measuredvbat = analogRead(VBATPIN);
      measuredvbat *= 2;    // we divided by 2, so multiply back
      //measuredvbat *= 3.3;  // Multiply by 3.3V, our reference voltage
      measuredvbat /= 1024; // convert to voltage
      Serial.print("VBat: " ); Serial.println(measuredvbat);
      ws2812fx.setColor(RED);
      if(measuredvbat>3.3)
       ws2812fx.setMode(FX_MODE_STATIC);
      else
       ws2812fx.setMode(FX_MODE_BLINK);     
}

void setup(void) 
{
  // set builtin LED to be an output pin
  pinMode(LED_BUILTIN, OUTPUT);
  digitalWrite(LED_BUILTIN, HIGH);

  #if defined(NEOPIXEL_POWER)
    // If this board has a power control pin, we must set it to output and high
    // in order to enable the NeoPixels. We put this in an #if defined so it can
    // be reused for other boards without compilation errors
    pinMode(NEOPIXEL_POWER, OUTPUT);
    digitalWrite(NEOPIXEL_POWER, HIGH);
  #endif

  // Turn on the I2C power by pulling pin HIGH.
  pinMode(NEOPIXEL_I2C_POWER, OUTPUT);
  digitalWrite(NEOPIXEL_I2C_POWER, HIGH);
  Serial.println("NEOPIXEL_I2C_POWER OK");

  Serial.begin(115200);

  // Wait for Serial port to open
  while (!Serial) {
    delay(10);
  }
  delay(500);
  Serial.println("Feather Star Pointer");

  /* Initialise the sensor */
  if(!bno.begin())
  {
    /* There was a problem detecting the BNO055 ... check your connections */
    Serial.print("Ooops, no BNO055 detected ... Check your wiring or I2C ADDR!");
    while(1);
  }

  ws2812fx.init();
  ws2812fx.setBrightness(32);
  ws2812fx.setSpeed(1000);
  ws2812fx.setColor(BLUE);
  ws2812fx.setMode(FX_MODE_STATIC);
  ws2812fx.start();
  ws2812fx.service();

  delay(1000);
  bno.setExtCrystalUse(true);
  delay(1000);
  SerialBT.begin("Feather Star Pointer"); //Bluetooth device name
  calibrate();
  displayBatteryCharge();
}


void loop(void) 
{ 
  if (SerialBT.available()) {
    char command=SerialBT.read();
    char response[30];
    Serial.print(">");
    Serial.println(command);

    if(command=='Q') 
    {
      sensors_event_t event; 
      bno.getEvent(&event);
      
      int az=(int)((event.orientation.x)*8192.0/360.0);
      int alt=(int)((event.orientation.y)*8192.0/360.0);
      az=mod(az,8192)-4096;
      alt=mod(alt,8192)-4096;
      
      sprintf(response, "%i %i\n", az, alt);
      Serial.print("<");
      Serial.print(response);
      Serial.println(event.orientation.x);
      Serial.println(event.orientation.y);
      SerialBT.println(response);
      
    }
    if(command=='H')
    {
      snprintf(response, 20, "%u-%u\n", 8192, 8192);
      Serial.print("<");
      Serial.print(response);
      SerialBT.println(response);
    }
    if(command=='B')
    {
      float measuredvbat = analogRead(VBATPIN);
      measuredvbat *= 2;    // we divided by 2, so multiply back
      //measuredvbat *= 3.3;  // Multiply by 3.3V, our reference voltage
      measuredvbat /= 1024; // convert to voltage
      Serial.print("VBat: " ); Serial.println(measuredvbat);
      SerialBT.print("VBat: " ); SerialBT.println(measuredvbat);
    }
  }

  if(batteryTimer.isReady()) {
    displayBatteryCharge();
    batteryTimer.reset();
  }

  ws2812fx.service();
}

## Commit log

2022-09-25 Initial import
    [BOSL2logo.scad, ESP32FeatherV2.stl, YAPPgenerator_v15.scad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]
2022-09-25 Remove files
    [base.stl, feather_finder.stl, holder.stl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]
2022-09-26 Enable bluetooth serial before calibration
2022-09-30 Battery status
    Main LED turns orange when battery is low.
2022-09-30 Adjust holder fit
    [feather_finder.scad]
2022-10-01 Switch to red light / blinking
2022-10-07 Add a switch
    [YAPPgenerator_v15.scad, base.stl, feather_finder.scad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]

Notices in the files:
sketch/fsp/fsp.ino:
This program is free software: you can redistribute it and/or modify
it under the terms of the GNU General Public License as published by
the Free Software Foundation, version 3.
